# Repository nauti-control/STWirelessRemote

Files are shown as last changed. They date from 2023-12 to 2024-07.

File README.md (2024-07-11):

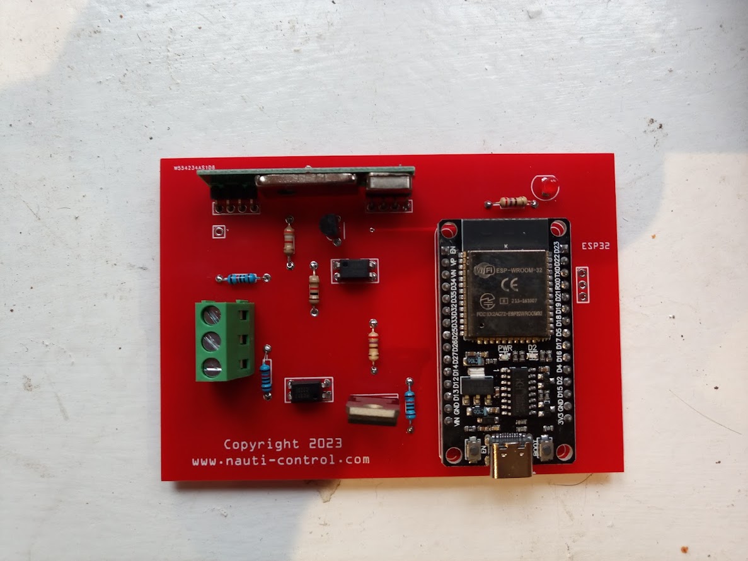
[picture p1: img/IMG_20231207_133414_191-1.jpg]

# ST Wireless Remote Controller

Open Source Wireless remote for Raymarine Seatalk  autopilotsincluding ST1000/ST2000. Compatible with all devices that work with the Raymarine S100, also controls other insturments such ST60 speed timer. Allows controlling of autopilot and various raymarine displays using 433mhz remote as well as mobile/tablet using built in WIFI Access Point. 

Aside from the remote functionality the connection to the seatalk bus allows us to read signals and decode other instrument data such as wind, speed , depth etc . Currently developing Seatalk -> NMEA 183 TCPIP transposer to allow Open CPN (and other such applications) to use the seatalk data , this would be done again over the wireless connection. This is currently under development . Other ideas for the future include a man over board mode where it'll set the heading nose to wind . These will be documented once completed on the main https://www.nauti-control.com website.

See how to setup box and demo on our youtube channel.
<br/>
https://youtu.be/EBTYceL7NpY

V2 Firmware is in a private repo while in Beta available to top level sponsors and supporters who buy a premade box directly from our shop.
<br/>
https://github.com/sponsors/nauti-control

# Compatibility

Works with all auto pilots that use classic Seatalk interface.

ST4000,ST4000+,ST5000,ST5000+,ST6000,ST6000+,ST6001,ST6001+,ST6002,ST6002+,ST7000,ST7000+,ST7001+,ST7002,ST7002+,ST8001,ST8001+,ST8002,ST8002+RayPilot 650

ST1000,ST1000+,ST2000,ST2000+

ST3000,ST4000,ST5000,ST6000,ST7000,Autohelm Sport pilot,Autohelm Sport pilot +
 
Type 100,Type 300,Type 150,Type 400,S1000,Sport pilot,sport pilot +,Smartpilot: S1,S1G,S2,S2G,S3,S3G,SP1,SPX5,SPX10 ,SPX30,SPX40,ST70P

ST60 Speed + Tri Data Displays (Timer)

Also works with newer autopilots with additional adapter for Seatalk 1 to Seatalk NG

https://www.raymarine.com/en-us/our-products/networking-and-accessories/seatalk/seatalk-1-to-seatalk-ng-convertor

Evolution EV100 , 150, 200 , 300 & 400

# Software
The code is written in C++ using platform IO . I use Visual Code as my editor . The firmware uses soft serial with the parity bit acting at the 9th bit that seatalk protocol uses.  The seatalk datagrams I have been using an excellent technical guide by Thomas Knauf http://thomasknauf.de/rap/seatalk2.htm . There is two parts to the code 1. The main firmware 2. A mini web application for settings the button mapping settings as well as allowing the device to be controlled from a mobile device . This is written to the esp32 spiffs. These get built and uploaded to the ESP32 seperately from with the platform IO extension in Visual Code.

# Hardware

The PCB design is fairly simple and uses an ESP32 devkit 30 pin board along with optocouplers to provide some isolation between the seatalk 12v and 3.3v of the ESP32 . A 7805 is used to drop the 12v down to 5v to feed the ESP32 . I found using 12v directly on the vin caused major issues and burnt out the onboard regulator on certain boards . The 7805 does get quite hot but i've done a burn in test for several weeks continious use and no issues on the bench. The receiver is a RXb6 and the current firmware has support for mapping to 8 buttons the different remote functionality. 

THe circuit design was created using the open source fritzing tool and source file is available in the repo along with generated gerbers used for making the PCBs . 

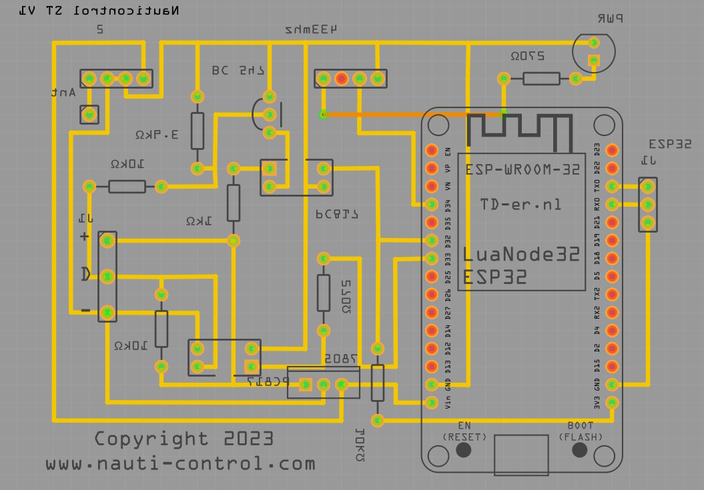
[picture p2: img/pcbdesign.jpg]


The case design was created using tinker cad and you can view the original here https://www.tinkercad.com/things/47GMuNnkxJl-nauticontrol-seatalk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  

STLS are included in the repo and ready to 3D print.

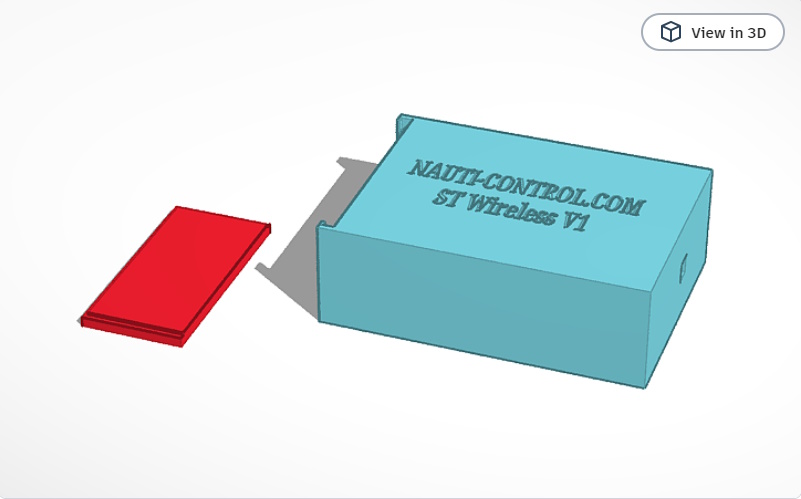
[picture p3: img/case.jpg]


You can purchase a fully hand built Wireless Controller from our online store which will help support ongoing development and new features <br/>
https://nauti-control.com/product/st-wireless-controller-fully-built-with-4-button-remote/<br/>
This includes a remote , 3d printed case and fully built PCB with latest firmware pre-installed , just plug into your seatalk system and go.<br/>

Bill Of Materials with links that will support on going development through affiliation or direct purchase.

1 x PCB - https://nauti-control.com/product/st-wireless-remote-controller-pcb/<br/>
1 x ESP32 - https://s.click.aliexpress.com/e/_DD5c10v <br />
1 x RXB6 433Mhz Superheterodyne Receiver - https://s.click.aliexpress.com/e/_DCJstw9 <br />
1 x 4 Button Remote https://nauti-control.com/product/4-button-wireless-remote-for-st-wireless-remote-controller/<br />
1 x 5v Voltage REgulator - https://s.click.aliexpress.com/e/_DmOF9RV <br />
1 x BC547 Transister - https://s.click.aliexpress.com/e/_DCKfQwp <br />
2 x 270ohm 1/4W Resistor - https://s.click.aliexpress.com/e/_DkgFIJ7 <br />
1 x 1kohm 1/4 Resistor - https://s.click.aliexpress.com/e/_DkgFIJ7 <br />
1 x 3.9kohm 1/4 Resistor -https://s.click.aliexpress.com/e/_DkgFIJ7 <br />
3 x 10kohm 1/4 Resistor - https://s.click.aliexpress.com/e/_DkgFIJ7 <br />
2 x PC817 Optocoupler -https://s.click.aliexpress.com/e/_DEU20qv <br />
1 x PCB Terminal Block 5.00mm pitch - https://s.click.aliexpress.com/e/_DFGZrcp <br />
1 x 433mhz Antenna https://s.click.aliexpress.com/e/_DDclB9J <br/>

Donate to support on going development and features.
https://nauti-control.com/donate/

Beta Code for next version is available to top tier sponsors , visit my sponsor page to support ongoing development and gain early access to all updates.
https://github.com/sponsors/nauti-control

# Disclaimer
I provide all hardware and software without liability or gaurantees as expressed by the GPL licence this has been released under <br/>

To avoid risk of damage ensure wiring is done correctly and while the system is off to avoid shorting or reverse polarity.

# Follow us on socials.

https://www.facebook.com/nauti-control/<br/>
https://www.instagram.com/nauticontrol<br/>
https://www.youtube.com/@nauti-control/ <br/>

# Facebook Support Group
https://www.facebook.com/groups/307695028303840<br/>

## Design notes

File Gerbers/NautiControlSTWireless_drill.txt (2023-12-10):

; NON-PLATED HOLES START AT T1
; THROUGH (PLATED) HOLES START AT T100
M48
INCH
T100C0.043307
T101C0.038000
T102C0.015748
T103C0.035000
T104C0.039370
T105C0.031497
T106C0.035050
%
T100
X033197Y010056
X033197Y014056
X033197Y012056
T101
X003197Y016056
X034197Y021056
X003197Y015056
X003197Y017056
T102
X021197Y021056
X011197Y021056
T103
X025197Y007056
X024197Y021056
X028197Y007056
X011197Y023056
X024197Y017056
X024197Y018056
X021197Y018056
X024197Y020056
X021197Y017056
X030197Y017056
X024197Y022056
X021197Y013056
X021197Y009056
X028197Y022056
X018197Y004056
X028197Y018056
X007197Y023056
X028197Y008056
X018197Y008056
X034197Y017056
X025197Y008056
X026197Y014056
X030197Y007056
X030197Y011056
X026197Y018056
T104
X020197Y023056
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

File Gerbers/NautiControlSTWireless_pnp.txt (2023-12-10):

*Pick And Place List
*Company=
*Author=
*eMail=
*
*Project=NautiControlSTWireless
*Date=13:00:20
*CreatedBy=Fritzing 0.9.10b.2022-07-01.CD-2134-0-40d23c29
*
*
*Coordinates in mm, always center of component
*Origin 0/0=Lower left corner of PCB
*Rotation in degree (0-360, math. pos.)
*
*No;Value;Package;X;Y;Rotation;Side;Name
1;;DIP (Dual Inline) [THT];37.2806;-44.7913;0;Bottom;IC1_B
2;;;53.8425;-53.4843;0;Bottom;Via1
3;;DIP (Dual Inline) [THT];37.2806;-44.6206;0;Bottom;IC1_E
4;5V;to220-igo;53.8426;-15.7018;0;Bottom;7805
5;0.030;5 mm [THT];15.7425;-61.7953;0;Bottom;PWR
6;;DIP (Dual Inline) [THT];57.6526;-44.5943;0;Bottom;PC817
7;;DIP (Dual Inline) [THT];34.5575;-44.6721;0;Bottom;IC1_PWR
8;;DIP (Dual Inline) [THT];37.1042;-19.5616;0;Bottom;IC1_C
9;;DIP (Dual Inline) [THT];24.6969;-38.4151;0;Bottom;IC1_D
10;;DIP (Dual Inline) [THT];19.4885;-40.7844;0;Bottom;IC1_A
11;;DIP (Dual Inline) [THT];42.3485;-43.3244;0;Bottom;IC1_A
12;1k;THT;66.5426;-40.7843;90;Bottom;1kO
13;;DIP (Dual Inline) [THT];37.2806;-44.5635;0;Bottom;IC1_F
14;;TO92 [THT];61.5515;-53.6748;-90;Bottom;BC 547
15;;DIP (Dual Inline) [THT];37.2806;-44.6776;0;Bottom;IC1_D
16;;DIP (Dual Inline) [THT];37.2806;-44.5635;0;Bottom;IC1_F
17;270;THT;53.8426;-28.0843;90;Bottom;270O
18;;;87.3959;-25.5669;0;Bottom;TXT3
19;;DIP (Dual Inline) [THT];37.2806;-44.6206;0;Bottom;IC1_E
20;;DIP (Dual Inline) [THT];37.2806;-44.7344;0;Bottom;IC1_C
21;;DIP (Dual Inline) [THT];37.2806;-44.6776;0;Bottom;IC1_D
22;;DIP (Dual Inline) [THT];37.2806;-44.7913;0;Bottom;IC1_B
23;;DIP (Dual Inline) [THT];37.2806;-44.5635;0;Bottom;IC1_F
24;;;87.5631;-35.9489;0;Bottom;TXT3
25;;;87.3809;-30.6669;0;Bottom;TXT3
26;;DIP (Dual Inline) [THT];37.2806;-44.6206;0;Bottom;IC1_E
27;;THT;8.12264;-40.7843;0;Bottom;J1
28;;;28.4425;-53.4843;0;Bottom;Via2
29;;DIP (Dual Inline) [THT];37.2806;-44.7344;0;Bottom;IC1_C
30;;DIP (Dual Inline) [THT];37.2806;-44.8481;0;Bottom;IC1_A
31;;DIP (Dual Inline) [THT];67.8126;-19.1943;180;Bottom;PC817
32;;DIP (Dual Inline) [THT];37.2806;-44.7344;0;Bottom;IC1_C
33;3.9k;THT;71.6226;-50.9443;90;Bottom;3.9kO
34;;THT;86.8626;-53.4843;0;Bottom;Ant
35;10k;THT;46.2226;-15.3843;90;Bottom;10kO
36;;THT;84.3226;-30.6243;0;Bottom;J1
37;;DIP (Dual Inline) [THT];37.2806;-44.8481;0;Bottom;IC1_A
38;10k;THT;81.7826;-43.3243;0;Bottom;10kO
39;;DIP (Dual Inline) [THT];34.5575;-44.6721;0;Bottom;IC1_PWR
40;;;25.8762;-28.5368;90;Bottom;ESP32
41;;DIP (Dual Inline) [THT];34.5575;-44.6721;0;Bottom;IC1_PWR
42;;DIP (Dual Inline) [THT];37.2806;-44.7913;0;Bottom;IC1_B
43;;;73.5592;-7.4764;0;Bottom;TXT2
44;;DIP (Dual Inline) [THT];37.2806;-44.6776;0;Bottom;IC1_D
45;;;74.0365;-4.0014;0;Bottom;TXT1
46;;DIP (Dual Inline) [THT];37.1042;-44.8481;0;Bottom;IC1_A
47;;DIP (Dual Inline) [THT];21.8642;0.815223;0;Bottom;IC1_B
48;;THT;50.0326;-58.5643;90;Bottom;433mhz
49;10k;THT;76.7026;-23.0043;90;Bottom;10kO
50;;DIP (Dual Inline) [THT];60.1285;-30.6816;0;Bottom;IC1_B
51;270;THT;23.3626;-58.5643;0;Bottom;270O
52;;THT;83.0526;-58.5643;90;Bottom;2

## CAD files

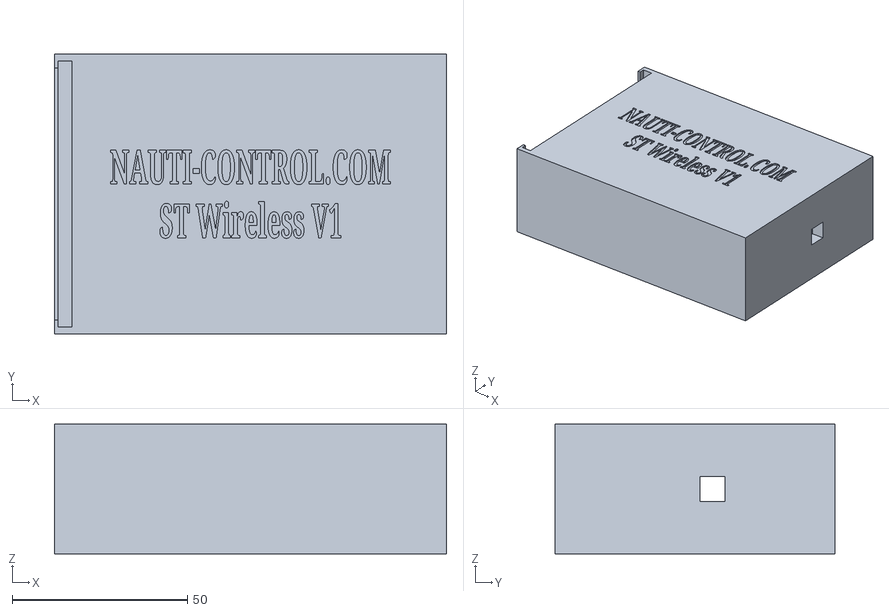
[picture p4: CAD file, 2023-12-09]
STL/NautiControl Seatalk Box.stl
112.0 x 80.0 x 37.0

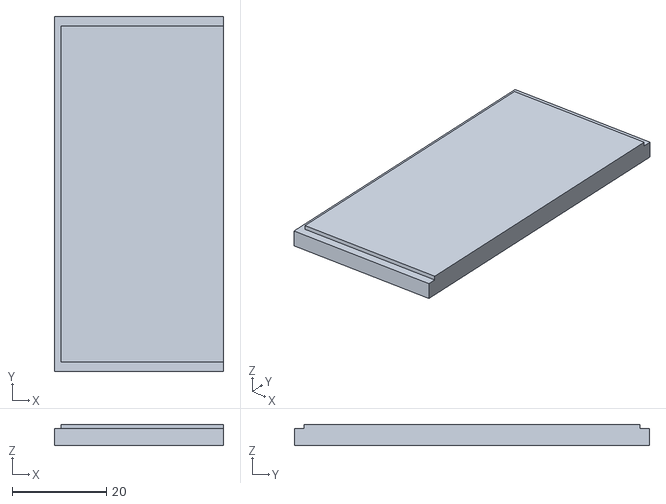
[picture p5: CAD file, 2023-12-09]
STL/NautiControl Seatalk Lid.stl
36.0 x 75.5 x 4.50

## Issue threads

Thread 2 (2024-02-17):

compile error

wjquigs11, 2024-02-17:
I get several errors compiling in VS Code. Most of the errors are for missing include files because they're referenced with "\" instead of "/" which is easy to fix, but I also got a link error:
Linking .pio/build/nodemcu-32s/firmware.elf
.pio/build/nodemcu-32s/lib1e2/libEspSoftwareSerial.a(SoftwareSerial.cpp.o): in function `std::function<void ()>::operator()() const':
/Users/user/.platformio/packages/toolchain-xtensa-esp32/xtensa-esp32-elf/include/c++/8.4.0/bits/std_function.h:686:(.iram1.66[delegate::detail::DelegateImpl<void*, void>::operator()() const]+0x24): dangerous relocation: l32r: literal placed after use: .literal._ZNK8delegate6detail12DelegateImplIPvvEclEv
collect2: error: ld returned 1 exit status
*** [.pio/build/nodemcu-32s/firmware.elf] Error 1
======================================================= [FAILED] Took 13.16 seconds =======================================================

I don't really understand why, but google turned up [this](https://stackoverflow.com/questions/19532826/what-does-a-dangerous-relocation-error-mean), so I modified platformio.ini and added:

build_flags =
	-mtext-section-literals

Let me know if you want a pull request.

nauti-control, 2024-02-17:
I'm fairly new to PlatformIO so may well be down to me! I'm not having issues and switching over to check that branch now just to make sure . Would there be some other settings in our visual code/platformio that could affect this?

First thing is that the software serial library looks to be at fault in your message, you'd expect that should just work without issue.

It's a strange one! I'd like to understand why the difference in behaviour though.

nauti-control, 2024-02-17:
*  Executing task in folder STWirelessRemote: C:\Users\user\.platformio\penv\Scripts\platformio.exe run --environment nodemcu-32s

Processing nodemcu-32s (platform: espressif32; board: nodemcu-32s; framework: arduino)
-----------------------------------------------------------------------------------------------------------------------------------------------------------------------------------Verbose mode can be enabled via `-v, --verbose` option
CONFIGURATION: https://docs.platformio.org/page/boards/espressif32/nodemcu-32s.html
PLATFORM: Espressif 32 (5.3.0) > NodeMCU-32S
HARDWARE: ESP32 240MHz, 320KB RAM, 4MB Flash
DEBUG: Current (cmsis-dap) External (cmsis-dap, esp-bridge, esp-prog, iot-bus-jtag, jlink, minimodule, olimex-arm-usb-ocd, olimex-arm-usb-ocd-h, olimex-arm-usb-tiny-h, olimex-jtag-tiny, tumpa)
PACKAGES:
 - framework-arduinoespressif32 @ 3.20006.221224 (2.0.6)
 - tool-esptoolpy @ 1.40400.0 (4.4.0)
 - toolchain-xtensa-esp32 @ 8.4.0+2021r2-patch5
LDF: Library Dependency Finder -> https://bit.ly/configure-pio-ldf
LDF Modes: Finder ~ chain, Compatibility ~ soft
Found 39 compatible libraries
Scanning dependencies...
Dependency Graph
|-- rc-switch @ 2.6.4
|-- ESP Async WebServer @ 1.2.3+sha.f71e3d4
|-- EspSoftwareSerial @ 7.0.0
|-- I2Cdevlib-HMC5883L @ 1.0.0
|-- SPIFFS @ 2.0.0
|-- AsyncTCP @ 1.1.1
|-- WiFi @ 2.0.0
|-- Preferences @ 2.0.0
Building in release mode
Compiling .pio\build\nodemcu-32s\src\Lib\BoxWebServer.cpp.o
Compiling .pio\build\nodemcu-32s\src\Lib\BoxWifi.cpp.o
Compiling .pio\build\nodemcu-32s\src\Lib\CommandStack.cpp.o
Compiling .pio\build\nodemcu-32s\src\Lib\Nmea.cpp.o
Compiling .pio\build\nodemcu-32s\src\Lib\NmeaServer.cpp.o
Compiling .pio\build\nodemcu-32s\src\Lib\Options.cpp.o
Compiling .pio\build\nodemcu-32s\src\Lib\RemoteControl.cpp.o
Compiling .pio\build\nodemcu-32s\src\Lib\SeaTalk.cpp.o
Compiling .pio\build\nodemcu-32s\src\Lib\SignalManager.cpp.o
Compiling .pio\build\nodemcu-32s\src\main.cpp.o
Building .pio\build\nodemcu-32s\bootloader.bin
Generating partitions .pio\build\nodemcu-32s\partitions.bin
esptool.py v4.4
Creating esp32 image...
Merged 1 ELF section
Successfully created esp32 image.
Compiling .pio\build\nodemcu-32s\libe60\rc-switch\RCSwitch.cpp.o
Compiling .pio\build\nodemcu-32s\libd4f\AsyncTCP\AsyncTCP.cpp.o
Compiling .pio\build\nodemcu-32s\lib5e1\FS\FS.cpp.o
Compiling .pio\build\nodemcu-32s\lib5e1\FS\vfs_api.cpp.o
Archiving .pio\build\nodemcu-32s\libe60\librc-switch.a
Compiling .pio\build\nodemcu-32s\lib152\WiFi\WiFi.cpp.o
Compiling .pio\build\nodemcu-32s\lib152\WiFi\WiFiAP.cpp.o
Archiving .pio\build\nodemcu-32s\libd4f\libAsyncTCP.a
Compiling .pio\build\nodemcu-32s\lib152\WiFi\WiFiClient.cpp.o
Archiving .pio\build\nodemcu-32s\lib5e1\libFS.a
Compiling .pio\build\nodemcu-32s\lib152\WiFi\WiFiGeneric.cpp.o
Compiling .pio\build\nodemcu-32s\lib152\WiFi\WiFiMulti.cpp.o
Compiling .pio\build\nodemcu-32s\lib152\WiFi\WiFiSTA.cpp.o
Compiling .pio\build\nodemcu-32s\lib152\WiFi\WiFiScan.cpp.o
Compiling .pio\build\nodemcu-32s\lib152\WiFi\WiFiServer.cpp.o
Compiling .pio\build\nodemcu-32s\lib152\WiFi\WiFiUdp.cpp.o
Compiling .pio\build\nodemcu-32s\lib953\ESP Async WebServer\AsyncEventSource.cpp.o
Compiling .pio\build\nodemcu-32s\lib953\ESP Async WebServer\AsyncWebSocket.cpp.o
Compiling .pio\build\nodemcu-32s\lib953\ESP Async WebServer\SPIFFSEditor.cpp.o
Archiving .pio\build\nodemcu-32s\lib152\libWiFi.a
Compiling .pio\build\nodemcu-32s\lib953\ESP Async WebServer\WebAuthentication.cpp.o
Compiling .pio\build\nodemcu-32s\lib953\ESP Async WebServer\WebHandlers.cpp.o
Compiling .pio\build\nodemcu-32s\lib953\ESP Async WebServer\WebRequest.cpp.o
Compiling .pio\build\nodemcu-32s\lib953\ESP Async WebServer\WebResponses.cpp.o
Compiling .pio\build\nodemcu-32s\lib953\ESP Async WebServer\WebServer.cpp.o
Compiling .pio\build\nodemcu-32s\libe20\EspSoftwareSerial\SoftwareSerial.cpp.o
Compiling .pio\build\nodemcu-32s\lib8eb\Wire\Wire.cpp.o
Compiling .pio\build\nodemcu-32s\lib48a\I2Cdevlib-Core\I2Cdev.cpp.o
Archiving .pio\build\nodemcu-32s\lib953\libESP Async WebServer.a
Compiling .pio\build\nodemcu-32s\libf8d\I2Cdevlib-HMC5883L\HMC5883L.cpp.o
Archiving .pio\build\nodemcu-32s\libe20\libEspSoftwareSerial.a
Compiling .pio\build\nodemcu-32s\lib6d2\SPIFFS\SPIFFS.cpp.o
Archiving .pio\build\nodemcu-32s\lib8eb\libWire.a
Compiling .pio\build\nodemcu-32s\lib41d\Preferences\Preferences.cpp.o
Archiving .pio\build\nodemcu-32s\lib48a\libI2Cdevlib-Core.a
Compiling .pio\build\nodemcu-32s\FrameworkArduino\Esp.cpp.o
Archiving .pio\build\nodemcu-32s\libf8d\libI2Cdevlib-HMC5883L.a
Compiling .pio\build\nodemcu-32s\FrameworkArduino\FirmwareMSC.cpp.o
Compiling .pio\build\nodemcu-32s\FrameworkArduino\FunctionalInterrupt.cpp.o
Archiving .pio\build\nodemcu-32s\lib6d2\libSPIFFS.a
Compiling .pio\build\nodemcu-32s\FrameworkArduino\HWCDC.cpp.o
Compiling .pio\build\nodemcu-32s\FrameworkArduino\HardwareSerial.cpp.o
Archiving .pio\build\nodemcu-32s\lib41d\libPreferences.a
Compiling .pio\build\nodemcu-32s\FrameworkArduino\IPAddress.cpp.o
Compiling .pio\build\nodemcu-32s\FrameworkArduino\IPv6Address.cpp.o
Compiling .pio\build\nodemcu-32s\FrameworkArduino\MD5Builder.cpp.o
Compiling .pio\build\nodemcu-32s\FrameworkArduino\Print.cpp.o
Compiling .pio\build\nodemcu-32s\FrameworkArduino\Stream.cpp.o
Compiling .pio\build\nodemcu-32s\FrameworkArduino\StreamString.cpp.o
Compiling .pio\build\nodemcu-32s\FrameworkArduino\Tone.cpp.o
Compiling .pio\build\nodemcu-32s\FrameworkArduino\USB.cpp.o
Compiling .pio\build\nodemcu-32s\FrameworkArduino\USBCDC.cpp.o
Compiling .pio\build\nodemcu-32s\FrameworkArduino\USBMSC.cpp.o
Compiling .pio\build\nodemcu-32s\FrameworkArduino\WMath.cpp.o
Compiling .pio\build\nodemcu-32s\FrameworkArduino\WString.cpp.o
Compiling .pio\build\nodemcu-32s\FrameworkArduino\base64.cpp.o
Compiling .pio\build\nodemcu-32s\FrameworkArduino\cbuf.cpp.o
Compiling .pio\build\nodemcu-32s\FrameworkArduino\esp32-hal-adc.c.o
Compiling .pio\build\nodemcu-32s\FrameworkArduino\esp32-hal-bt.c.o
Compiling .pio\build\nodemcu-32s\FrameworkArduino\esp32-hal-cpu.c.o
Compiling .pio\build\nodemcu-32s\FrameworkArduino\esp32-hal-dac.c.o
Compiling .pio\build\nodemcu-32s\FrameworkArduino\esp32-hal-gpio.c.o
Compiling .pio\build\nodemcu-32s\FrameworkArduino\esp32-hal-i2c-slave.c.o
Compiling .pio\build\nodemcu-32s\FrameworkArduino\esp32-hal-i2c.c.o
Compiling .pio\build\nodemcu-32s\FrameworkArduino\esp32-hal-ledc.c.o
Compiling .pio\build\nodemcu-32s\FrameworkArduino\esp32-hal-matrix.c.o
Compiling .pio\build\nodemcu-32s\FrameworkArduino\esp32-hal-misc.c.o
Compiling .pio\build\nodemcu-32s\FrameworkArduino\esp32-hal-psram.c.o
Compiling .pio\build\nodemcu-32s\FrameworkArduino\esp32-hal-rgb-led.c.o
Compiling .pio\build\nodemcu-32s\FrameworkArduino\esp32-hal-rmt.c.o
Compiling .pio\build\nodemcu-32s\FrameworkArduino\esp32-hal-sigmadelta.c.o
Compiling .pio\build\nodemcu-32s\FrameworkArduino\esp32-hal-spi.c.o
Compiling .pio\build\nodemcu-32s\FrameworkArduino\esp32-hal-time.c.o
Compiling .pio\build\nodemcu-32s\FrameworkArduino\esp32-hal-timer.c.o
Compiling .pio\build\nodemcu-32s\FrameworkArduino\esp32-hal-tinyusb.c.o
Compiling .pio\build\nodemcu-32s\FrameworkArduino\esp32-hal-touch.c.o
Compiling .pio\build\nodemcu-32s\FrameworkArduino\esp32-hal-uart.c.o
Compiling .pio\build\nodemcu-32s\FrameworkArduino\firmware_msc_fat.c.o
Compiling .pio\build\nodemcu-32s\FrameworkArduino\libb64\cdecode.c.o
Compiling .pio\build\nodemcu-32s\FrameworkArduino\libb64\cencode.c.o
Compiling .pio\build\nodemcu-32s\FrameworkArduino\main.cpp.o
Compiling .pio\build\nodemcu-32s\FrameworkArduino\stdlib_noniso.c.o
Compiling .pio\build\nodemcu-32s\FrameworkArduino\wiring_pulse.c.o
Compiling .pio\build\nodemcu-32s\FrameworkArduino\wiring_shift.c.o
Archiving .pio\build\nodemcu-32s\libFrameworkArduino.a
Linking .pio\build\nodemcu-32s\firmware.elf
Retrieving maximum program size .pio\build\nodemcu-32s\firmware.elf
Checking size .pio\build\nodemcu-32s\firmware.elf
Advanced Memory Usage is available via "PlatformIO Home > Project Inspect"
RAM:   [=         ]  13.6% (used 44616 bytes from 327680 bytes)
Flash: [======    ]  63.9% (used 837349 bytes from 1310720 bytes)
Building .pio\build\nodemcu-32s\firmware.bin
esptool.py v4.4
Creating esp32 image...
Merged 25 ELF sections
Successfully created esp32 image.
========================================================================== [SUCCESS] Took 79.63 seconds ==========================================================================
 *  Terminal will be reused by tasks, press any key to close it.

Closed 2024-02-26.

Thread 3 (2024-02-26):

Port to SignalK SensESP

UnderSampled, 2024-02-26:
For more complicated boat networks, where existing NMEA0183, NMEA2000, Seatalk, wifi, USB, and bluetooth devices all live together, SignalK is meant to help bridge the interfaces with a common server.

Info about the SignalK project: http://signalk.org/

In addition to the server, the SignalK project also maintains a framework for ESP-based sensors to communicate with it. It is well thought out, with a dashboard in the default access-point mode for configuring wifi and (optional) connection to the server, and an asynchronous event-based architecture from ReactESP.

GitHub for the SensESP firmware framework: https://github.com/SignalK/SensESP

ReactESP: https://github.com/mairas/ReactESP

Because the rest of SenseESP is quite similar to this project (PlatformIO, Arduino/C++, an ESP32, and ESP Async Webserver), I believe that porting to their codebase will not be difficult, and is the easiest way to gain some important functionality.

---

For my own part, I need SignalK for my connection to SeaTalk to be useful, as my ultimate goal is to provide the GPS, and course for "track" mode through SignalK. As well, I look forward to finally getting wind and autopilot data into SignalK, so it can be shown in Freeboard (a locally hosted web-based chartplotter) and OpenCPN combined with the AIS data.

I have been trying to do this for several years, and already had a non-functional prototype. I was able to get your firmware on it, but I still have some hardware issues to work out that prevent me from contributing already.

nauti-control, 2024-02-26:
Hi there, yes i have worked with signal K before . One thing you'll notice when working with ESP32 a bit if you have a bluetooth and web (async libraries) you soon run out of heap space and things start turning a bit quirky so i'm trying to avoid adding more bloat.

In version 2 that i'm currently working on and will be available to supporters first will have wireless connection abilities with TCPIP so will connect to open marine and interface through signal K using NMEA 0183 async TCPIP . There are however other things such as connecting directly to OPEN CPN that this would support from a laptop/tablet etc and other apps such as navionics. I'd rather not focus on one particular use case , though I do feel  what you are looking will be covered by what i'm doing.

I'll hopefully get some demos up on the socials and website on version two working with Signal K for the data points such as wind speed etc.

UnderSampled, 2024-02-28:
Will this be bi-directional? Providing the GPS and track data to my autopilot would be a huge improvement!

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
Sincerely,
UnderSampled

Closed 2024-02-26.

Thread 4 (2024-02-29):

Build Issue on fresh install

nauti-control, 2024-02-29:
Error happening on fresh install of VC without platformio plugin installed previously
.pio\build\esp32doit-devkit-v1\lib6e4\libEspSoftwareSerial.a(SoftwareSerial.cpp.o): In function `std::function<void ()>::operator()() const':
C:\ReporOwn\STWirelessRemote/.pio\libdeps\esp32doit-devkit-v1\EspSoftwareSerial\src/SoftwareSerial.cpp:670:(.iram1.54[delegate::detail::DelegateImpl<void*, void>::operator()() const]+0x22): dangerous relocation: l32r: literal placed after use: .literal._ZNK8delegate6detail12DelegateImplIPvvEclEv
collect2.exe: error: ld returned 1 exit status

nauti-control, 2024-02-29:
Ok this one had me baffled , it does build fine on my build machine however there are a few things that can differer and I was able to replicate on another PC i use.
1. The espressif platform version isnt tied to the platform.io file and needs upgraded manually .
2. The one that caused the break in my case was the espsoftwareserial . I have specified version 7.0.0 which works however whenever you do a fresh install it pulls down 7.0.1 which doesnt work . I've worked around this changing the library dependency to point directly at the tag in git rather than the library . This fixed the issue for the build.
The joys of open source and dependencies on other libraries .
Will get commits up this evening to sort it out for others. Not my code!

Closed 2024-02-29.

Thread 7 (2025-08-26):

Technical questions

arturslogins, 2025-08-26:
Hello,

I recently came across your YouTube channel and GitHub repository while searching for information on how to build a remote control system for a boat. Your project immediately caught my attention, as it seems to provide many of the features I am looking for and demonstrates a very practical approach to integrating with Raymarine Seatalk autopilots and other instruments.

While exploring your project, I had a few questions that I hope you might be able to clarify.

Does the current ST Wireless Remote Controller firmware support any integration with GSM/4G/5G or satellite modules to enable remote control outside of the local WiFi or 433 MHz range?

If not, is the software architecture (ESP32 firmware and web interface) designed in a way that would allow extensibility with such communication modules (e.g., SIM800, SIM7600, Iridium RockBLOCK, etc.)?

If remote control is not planned, would you consider allowing the community to develop an additional module (for example, by exposing an API that accepts commands over TCP/IP or MQTT from a GSM/satellite connection)?

How is communication with Raymarine autopilots and other marine control devices technically achieved – is it purely via the Seatalk protocol, or through unofficial/reverse-engineered protocols? Has this approach been tested with autopilots or navigation systems from other manufacturers as well?

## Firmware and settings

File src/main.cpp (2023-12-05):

#include <Arduino.h>
#include "Lib\RemoteControl.h"
#include "Lib\SeaTalk.h"
#include "Lib\BoxWifi.h"
#include "Lib\BoxWebServer.h"
#include "Lib\Options.h"
#include "Lib\SignalManager.h"
#include <SPIFFS.h>

RemoteControl *_remoteControl = nullptr;
SeaTalk *_seaTalk = nullptr;
BoxWifi *_boxWifi = nullptr;
Options *_options = nullptr;
SeaTalkData *_seaTalkData=nullptr;
SignalManager *_signalManager = nullptr;
BoxWebServer *_boxWebServer = nullptr;

void setup()
{

  Serial.begin(9600); // Serial out put for function checks with PC
                      // Initialize SPIFFS
  if (!SPIFFS.begin(true))
  {
    Serial.println("An Error has occurred while mounting SPIFFS");
    return;
  }
  _boxWifi = new BoxWifi();
  _seaTalkData= new SeaTalkData();
  _options = new Options();
  _signalManager= new SignalManager(_seaTalkData);
  _seaTalk = new SeaTalk(_signalManager);
  _remoteControl = new RemoteControl(_seaTalk, _options);
  _boxWebServer = new BoxWebServer(_seaTalk, _options);
}

void loop()
{
  _seaTalk->processMessages();
  _remoteControl->processRemote();
  _boxWebServer->ProcessCommands();
}

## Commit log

2023-10-18 Initial Commit V1
    [NautiControlSTWireless.fzz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]
2023-10-19 include pull up resistor
    [NautiControlSTWireless.fzz]
2023-10-19 Gerbers Update
    [NautiControlSTWireless.fzz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]
2023-11-20 Update Fritzing Set Two Layer to avoid jumpers
    [NautiControlSTWireless.fzz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]
2023-11-20 Update Fritzing To Double Layer.
    [NautiControlSTWireless.fzz]
2023-11-20 Fix Issue with fritzing layers.
    [NautiControlSTWireless.fzz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]
2023-12-05 Fix Bug Loading Options
    [NautiControlSTWireless.fzz]
2023-12-06 Added STL Files For Box
    [NautiControl Seatalk Box.stl, NautiControl Seatalk Lid.stl]
2023-12-08 Update Box Add Air Ventelation + Model
    [NautiControl Seatalk Box.stl, NautiControl Seatalk Lid.stl]
2023-12-09 Update Box To Add In Vents For 7805 doesnt seem to be needed but it'll no harm to let a bit more air in.
    [NautiControl Seatalk Box.stl, NautiControl Seatalk Lid.stl]
2023-12-10 Update Fritzing And Gerbers
    [NautiControlSTWireless.fzz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]
2023-12-15 add pcb design
2023-12-15 Add Case
